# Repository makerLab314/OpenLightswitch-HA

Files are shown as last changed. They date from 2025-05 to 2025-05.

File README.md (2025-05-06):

# OpenLightswitch-HA

OpenLightswitch-HA is an open-source hardware project that uses an Arduino Uno WiFi Rev2, SG90 servo motor, capacitive touch sensor, and 3D-printed parts to physically toggle European-style light switches. It supports MQTT for integration with systems like Home Assistant and allows local control via touch. The device is non-invasive and requires no changes to your home's wiring.

---

## Features

* MQTT-controlled light switch actuation
* Local control via capacitive touch sensor
* Customizable servo movement and timing
* Non-destructive mounting with 3D-printed holder
* Works with most European-style rocker switches

---

## Hardware Required

* Arduino Uno WiFi Rev2
* SG90 Micro Servo
* Capacitive Touch Sensor (e.g., TTP223)
* USB Power Supply (or 5V adapter)
* 3D-printed bracket and servo arm STL files in [STLs](https://github.com/makerLab314/OpenLightswitch-HA/tree/main/STLs)
* Jumper wires and optional mounting adhesive or tape

---

## Firmware Setup

1. Open the Arduino IDE and install the required libraries:

   * WiFiNINA
   * ArduinoMqttClient
   * Servo

2. Paste the firmware code [Firmware](https://github.com/makerLab314/OpenLightswitch-HA/blob/main/Lichtschalter_FINAL.ino) folder or from the code section below into a new sketch.

3. Modify these configuration values:

   ```cpp
   const char* ssid = "<YOUR_WIFI_SSID>";
   const char* password = "<YOUR_WIFI_PASSWORD>";
   const char* mqtt_server = "<YOUR_MQTT_BROKER_IP>";
   const char* mqtt_user = "<MQTT_USERNAME_IF_REQUIRED>";
   const char* mqtt_pass = "<MQTT_PASSWORD_IF_REQUIRED>";
   const char* command_topic = "<MQTT_TOPIC_COMMAND>";
   const char* state_topic = "<MQTT_TOPIC_STATE>";
   ```

4. Upload the sketch to your Arduino Uno WiFi Rev2.

---

## Home Assistant Configuration

To integrate the OpenLightswitch-HA into Home Assistant, you need to make sure your Home Assistant instance has MQTT properly set up. This means:

1. An MQTT broker (e.g. Mosquitto) is installed and running.
2. The broker is reachable from both Home Assistant and your Arduino device.
3. The Arduino is configured with the same credentials and IP address as used by the broker.
4. Home Assistant has MQTT integration enabled (either via the UI or `configuration.yaml`).

Once your MQTT broker is ready, add the following configuration to your `configuration.yaml` file:

```yaml
mqtt:
  switch:
    - name: "Office Light Switch (AMC)"
      unique_id: "office_lightswitch_amc"
      command_topic: "home/lightswitch/office/set"
      state_topic: "home/lightswitch/office/state"
      payload_on: "ON"
      payload_off: "OFF"
      state_on: "ON"
      state_off: "OFF"
      optimistic: false
      qos: 1
      retain: false
```

### Explanation of Parameters:

* **name**: The user-visible name in the Home Assistant dashboard.
* **unique\_id**: A unique identifier to ensure the device does not conflict with other entities.
* **command\_topic**: Topic that Home Assistant sends commands to.
* **state\_topic**: Topic from which Home Assistant reads the actual device state.
* **payload\_on / payload\_off**: Commands sent to the Arduino.
* **state\_on / state\_off**: Expected payloads reported by the Arduino.
* **optimistic**: Set to false because the Arduino reports back its state.
* **qos**: Use 1 for reliable delivery.
* **retain**: Set to false to avoid retaining stale commands.

### Optional: UI Integration

After restarting Home Assistant, the switch should automatically appear in the UI. If it doesn’t, go to *Settings > Devices & Services > MQTT* and check if the device is listed under discovered entities. You can also manually add it to a dashboard via *Settings > Dashboards*.

> ✅ Tip: You can test the setup by toggling the switch in the Home Assistant UI and verifying the Arduino responds with a tap movement and updates the state accordingly.

> ⚠️ Make sure your Home Assistant and Arduino are on the same network segment and your MQTT topics match exactly.

---
## Hardware Assembly

The OpenLightswitch-HA system was designed to be non-invasive and easy to install on standard European light switches.

### Components Required:

* Arduino Uno WiFi Rev2
* SG90 Micro Servo
* Capacitive touch sensor (e.g. TTP223)
* 3D-printed mounting bracket (custom-designed for EU switch frames)
* USB power supply (or equivalent stable 5V source)
* Jumper wires
* A M2x25 screw

### Assembly Instructions:

1. **Print the 3D Bracket**

   * Use the provided STL (3mf) files.
   * The bracket is designed to fit under the plastic frame of standard European light switches without damaging the wall or switch.
   * Make sure the print has enough infill to stay rigid under servo force.

2. **Install the Bracket**

   * Carefully remove the frame of your light switch (no tools required for most EU models).
   * Insert the 3D bracket under the frame and reattach the frame to hold the mount in place.
   * The servo arm should align with the light switch rocker so that it can tap either side.

3. **Attach Components**

   * Mount the SG90 servo onto the bracket using a M2x25 screw.
   * Connect the servo to pin 9 of the Arduino.
   * Connect the touch sensor to pin 2 of the Arduino.
   * Power the Arduino via USB or a stable 5V source.

> 🛠️ Make sure the servo has room to move the rocker switch in both directions. You may need to adjust the angle or bracket position slightly depending on your specific switch model.

> 💡 The design is reversible and requires no screws or adhesives on the wall, making it renter-friendly and easy to relocate.

---

## Operation

* Tapping the sensor toggles the switch manually (alternates ON/OFF).
* Sending `"ON"` or `"OFF"` to the configured MQTT command topic will trigger the servo.
* The Arduino reports its logical state back to the state topic after each action.

---

## License

This project is licensed under the GNU GPL v3 License. See `LICENSE` file for details.

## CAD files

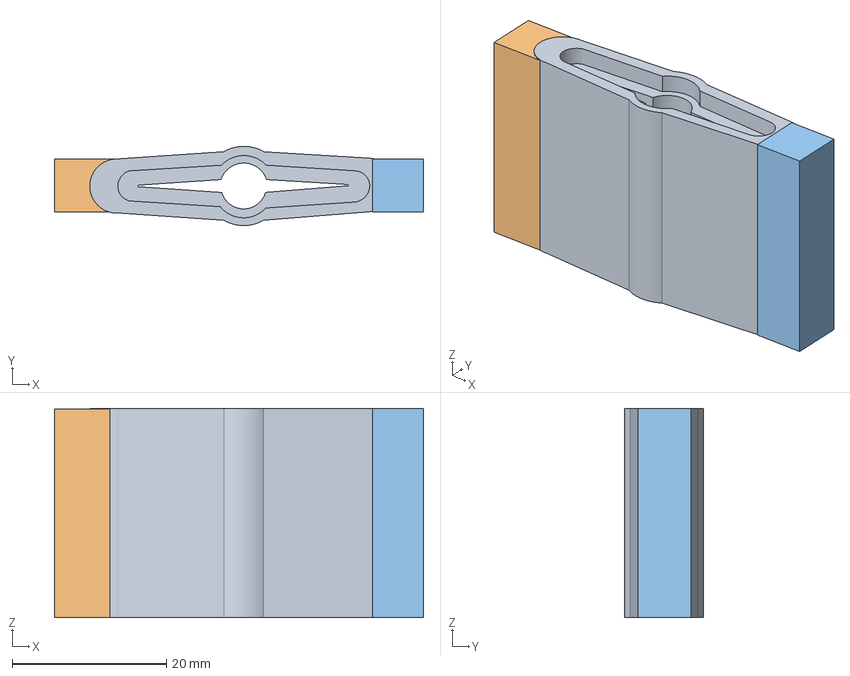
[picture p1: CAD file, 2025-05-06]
STLs/Servo Arm Adapter.3mf
47.8 x 10.3 x 27.1 mm
K_rper_03
K_rper_04
K_rper_04_(1)

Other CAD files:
STLs/Main Case.3mf

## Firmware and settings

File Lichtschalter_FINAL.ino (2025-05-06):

#include <SPI.h>          // Wird oft von WiFi-Bibliotheken benötigt
#include <WiFiNINA.h>     // <- Beibehalten für dein Board!
#include <ArduinoMqttClient.h> // <- Neue MQTT-Bibliothek aus dem Beispiel
#include <Servo.h>

// --- Konfiguration ---
// WLAN - BITTE ANPASSEN!
const char* ssid = "QuantumDATA";
const char* password = "81047475";

// MQTT Broker - BITTE ANPASSEN!
const char* mqtt_server = "192.168.1.117"; // z.B. "192.168.1.100"
const int mqtt_port = 1883;
const char* client_id = "arduinoLightSwitchOffice"; // Eindeutige Client-ID

// MQTT Zugangsdaten (falls benötigt, sonst leer lassen oder Zeilen auskommentieren)
const char* mqtt_user = "superuser";
const char* mqtt_pass = "homeassistant3Dffm";

// MQTT Topics
const char* command_topic = "home/lightswitch/office/set";
const char* state_topic = "home/lightswitch/office/state";

// Pins
const int servoPin = 9;
const int touchPin = 2;

// Servo-Parameter - BITTE ANPASSEN!
// *** WICHTIGE ÄNDERUNG HIER ***
const int servoCenterPosition = 90; // Mittelposition auf 90 Grad gesetzt
// *****************************
const int servoTapAngle = 50;       // Ausschlag beim Tippen in jede Richtung (Grad) - Ggf. anpassen!
const int servoTapHoldDelay = 150;  // Kurze Pause in der Tipp-Position (ms) - für Sichtbarkeit
const int servoReturnDelay = 50;   // Kurze Pause nach Rückkehr zur Mitte (ms) - zum Absetzen

// --- Globale Variablen ---
WiFiClient wifiClient;
MqttClient mqttClient(wifiClient); // MqttClient aus ArduinoMqttClient
Servo myServo;

// Zustandmanagement
bool lastTurnRight = false; // Speichert den *logischen* Zustand (ON=true, OFF=false) für MQTT
bool nextTapRight = true;   // Steuert die Richtung des *nächsten manuellen Tipps* (true=rechts, false=links)

// Touch Sensor Debounce
long lastTouchTime = 0;
const long debounceDelay = 200; // Entprellzeit für den Touchsensor (ms)

// MQTT Reconnect Timing
unsigned long lastReconnectAttempt = 0;

// --- Prototypen ---
void connectWiFi();
void connectMQTT();
void publishState();
void performTap(bool goRight); // Funktion für die Tipp-Bewegung
void checkTouchSensor();
void onMqttMessage(int messageSize);

// --- Setup ---
void setup() {
  Serial.begin(115200);
  while (!Serial);

  Serial.println("Starting Smart Light Switch (Tap Control)...");

  // Pin für den Touchsensor als Eingang konfigurieren
  pinMode(touchPin, INPUT);
  Serial.println("Touch Pin initialized.");

  // Servo initialisieren
  myServo.attach(servoPin);
  myServo.write(servoCenterPosition); // Start in der neuen Mittelposition (90 Grad)
  lastTurnRight = false; // ANNAHME: Startzustand ist logisch "OFF"
  nextTapRight = true;   // Erster manueller Tipp geht nach rechts (ON)
  Serial.print("Servo initialized to center position: ");
  Serial.println(servoCenterPosition);
  delay(500); // Kurz warten, bis der Servo die Position erreicht hat

  // WLAN verbinden
  connectWiFi();

  // MQTT Client konfigurieren
  mqttClient.setId(client_id);
  // Falls Zugangsdaten benötigt werden:
  mqttClient.setUsernamePassword(mqtt_user, mqtt_pass);

  // MQTT Message Callback setzen
  mqttClient.onMessage(onMqttMessage);

  Serial.println("Setup finished.");
  // Die erste MQTT-Verbindung wird im Loop versucht
}

// --- Hauptschleife ---
void loop() {
  // 1. Prüfe WLAN Verbindung
  if (WiFi.status() != WL_CONNECTED) {
    Serial.println("WiFi connection lost. Attempting reconnect...");
    connectWiFi();
    // Nach erfolgreicher WLAN-Verbindung wird im nächsten Loop-Durchlauf
    // versucht, die MQTT-Verbindung aufzubauen (oder wiederherzustellen).
  } else {
    // Nur fortfahren, wenn WLAN verbunden ist
    // 2. Prüfe MQTT Verbindung und verbinde ggf. neu
    if (!mqttClient.connected()) {
      unsigned long now = millis();
      // Versuche nur alle 5 Sekunden einen Reconnect, um nicht zu spammen
      if (now - lastReconnectAttempt > 5000) {
        lastReconnectAttempt = now;
        connectMQTT();
      }
    } else {
      // 3. MQTT-Nachrichten verarbeiten, wenn verbunden
      mqttClient.poll();
    }
  }

  // 4. Prüfe den Touchsensor (immer prüfen, damit lokale Steuerung funktioniert)
  // Der Status wird nur gesendet, wenn MQTT verbunden ist (innerhalb publishState geprüft)
  checkTouchSensor();

  // Keine zusätzlichen Delays im Hauptloop, um reaktionsfähig zu bleiben
}

// --- Funktionen ---

void connectWiFi() {
  Serial.print("Checking WiFi module...");
  if (WiFi.status() == WL_NO_MODULE) {
    Serial.println(" Communication with WiFi module failed!");
    while (true); // Dauerhaft anhalten bei Hardwarefehler
  }
  Serial.println(" OK.");

  String fv = WiFi.firmwareVersion();
  Serial.print("WiFiNINA Firmware Version: ");
  Serial.println(fv);

  Serial.print("Attempting to connect to WPA SSID: ");
  Serial.println(ssid);
  WiFi.begin(ssid, password); // Start des Verbindungsversuchs

  unsigned long connectStart = millis();
  while (WiFi.status() != WL_CONNECTED) {
    delay(500);
    Serial.print(".");
    // Timeout nach z.B. 30 Sekunden, um nicht ewig zu blockieren
    if (millis() - connectStart > 30000) {
        Serial.println("\nConnection attempt timed out!");
        // Optional: Hier könnte man z.B. das Board neu starten
        // oder in einen Fehlerzustand gehen. Vorerst nur Meldung.
        return; // Verhindert Endlosschleife, wenn Verbindung nicht klappt
    }
  }

  Serial.println("\nWiFi connected!");
  Serial.print("IP Address: ");
  Serial.println(WiFi.localIP());
}

void connectMQTT() {
  // Versuche nur, wenn WLAN verbunden ist
  if (WiFi.status() != WL_CONNECTED) {
      Serial.println("MQTT connect skipped: WiFi not connected.");
      return;
  }

  Serial.print("Attempting MQTT connection to ");
  Serial.print(mqtt_server);
  Serial.print(":");
  Serial.println(mqtt_port);

  if (!mqttClient.connect(mqtt_server, mqtt_port)) {
    Serial.print("MQTT connection failed! Error code = ");
    Serial.println(mqttClient.connectError());
    // Nicht blockieren, nächster Versuch im Loop
  } else {
    Serial.println("MQTT connected!");
    Serial.print("Subscribing to command topic: ");
    Serial.println(command_topic);
    if (mqttClient.subscribe(command_topic)) {
        Serial.println("Subscription successful!");
        // Den aktuellen *logischen* Status sofort nach erfolgreicher Verbindung senden
        publishState();
    } else {
        Serial.println("Subscription failed!");
        // Optional: Verbindung trennen oder erneut versuchen?
        // mqttClient.disconnect(); // Oder einfach auf nächsten Poll warten
    }
  }
}

void publishState() {
  // Sende nur, wenn MQTT verbunden ist
  if (!mqttClient.connected()) {
    // Serial.println("Cannot publish state: MQTT not connected."); // Weniger Output im Normalbetrieb
    return;
  }

  const char* currentState = lastTurnRight ? "ON" : "OFF"; // Verwende den logischen Zustand
  Serial.print("Publishing logical state [");
  Serial.print(state_topic);
  Serial.print("]: ");
  Serial.println(currentState);

  // Sende mit Retain-Flag und QoS 1
  mqttClient.beginMessage(state_topic, strlen(currentState), true, 1);
  mqttClient.print(currentState);
  mqttClient.endMessage();
}

// Funktion für die schnelle Tipp-Bewegung
void performTap(bool goRight) {
  int targetPosition;
  int startPosition = servoCenterPosition; // Aktuelle Position ist immer die Mitte

  if (goRight) {
    Serial.println("Performing tap RIGHT (-> ON logic)");
    // Berechne Zielposition, begrenze auf 0-180
    targetPosition = constrain(startPosition + servoTapAngle, 0, 180);
  } else {
    Serial.println("Performing tap LEFT (-> OFF logic)");
    // Berechne Zielposition, begrenze auf 0-180
    targetPosition = constrain(startPosition - servoTapAngle, 0, 180);
  }

  Serial.print("Moving servo from ");
  Serial.print(startPosition);
  Serial.print(" to ");
  Serial.println(targetPosition);

  // Schnell zur Zielposition bewegen
  myServo.write(targetPosition);
  delay(servoTapHoldDelay); // Kurz halten für den "Tipp"-Effekt

  // Schnell zurück zur Mittelposition
  Serial.print("Returning servo to ");
  Serial.println(startPosition);
  myServo.write(startPosition);
  delay(servoReturnDelay); // Kurze Pause zum Absetzen
  Serial.println("Returned to center.");
}

void checkTouchSensor() {
  // Nur prüfen, wenn Debounce-Zeit abgelaufen ist
  long currentTime = millis();
  if (currentTime - lastTouchTime < debounceDelay) {
      return; // Zu früh für eine neue Berührung
  }

  int touchState = digitalRead(touchPin);

  // Prüfe auf HIGH Flanke
  if (touchState == HIGH) {
    Serial.println("Touch detected!");
    lastTouchTime = currentTime; // Debounce-Zeit neu starten

    // Führe den Tap in die Richtung aus, die 'nextTapRight' anzeigt
    performTap(nextTapRight);

    // Wechsle den *logischen* Zustand für MQTT
    lastTurnRight = !lastTurnRight;
    publishState(); // Sende den neuen logischen Zustand (prüft intern auf MQTT-Verbindung)

    // Wechsle die Richtung für den *nächsten manuellen* Tipp
    nextTapRight = !nextTapRight;

    // WICHTIG: Eine zusätzliche Wartezeit nach der Aktion ist hier nicht mehr nötig,
    // da der Debounce-Timer (lastTouchTime) direkt nach der Erkennung gesetzt wird
    // und die Servo-Bewegungszeit innerhalb des Debounce-Intervalls liegen sollte.
    // Der alte Delay wurde entfernt, um die Reaktionsfähigkeit zu erhöhen.
    // Stelle sicher, dass debounceDelay > (servoTapHoldDelay + servoReturnDelay) ist.
  }
}

// --- MQTT Callback Funktion ---
void onMqttMessage(int messageSize) {
  String topic = mqttClient.messageTopic();
  String payload = ""; // Umbenannt von message zu payload für Klarheit
  while (mqttClient.available()) {
    payload += (char)mqttClient.read();
  }

  Serial.print("Message received on topic: ");
  Serial.print(topic);
  Serial.print(", Payload: ");
  Serial.println(payload);

  if (topic == command_topic) {
    bool commandOn = (payload == "ON"); // Prüfe auf ON
    bool commandOff = (payload == "OFF"); // Prüfe auf OFF

    if (commandOn) {
      Serial.println("Received ON command");
      if (!lastTurnRight) { // Nur ausführen, wenn logischer Zustand OFF war
        Serial.println("Current state is OFF, performing tap RIGHT.");
        performTap(true);  // Tippe nach rechts
        lastTurnRight = true; // Setze logischen Zustand auf ON
        publishState();      // Veröffentliche neuen Zustand
        nextTapRight = false; // Nächster *manueller* Tipp soll nach links gehen (OFF)
      } else {
        Serial.println("Already ON (logically), no action needed.");
      }
    } else if (commandOff) {
      Serial.println("Received OFF command");
      if (lastTurnRight) { // Nur ausführen, wenn logischer Zustand ON war
        Serial.println("Current state is ON, performing tap LEFT.");
        performTap(false); // Tippe nach links
        lastTurnRight = false; // Setze logischen Zustand auf OFF
        publishState();       // Veröffentliche neuen Zustand
        nextTapRight = true;  // Nächster *manueller* Tipp soll nach rechts gehen (ON)
      } else {
          Serial.println("Already OFF (logically), no action needed.");
      }
    } else {
      Serial.print("Unknown command payload received: ");
      Serial.println(payload);
    }
  } else {
      Serial.print("Received message on unexpected topic: ");
      Serial.println(topic);
  }
}

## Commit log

2025-05-06 Rename Servo Arm Adapter.3mf to STLs/Servo Arm Adapter.3mf
    [Servo Arm Adapter.3mf]
2025-05-06 Rename Main Case.3mf to STLs/Main Case.3mf
    [Main Case.3mf]
